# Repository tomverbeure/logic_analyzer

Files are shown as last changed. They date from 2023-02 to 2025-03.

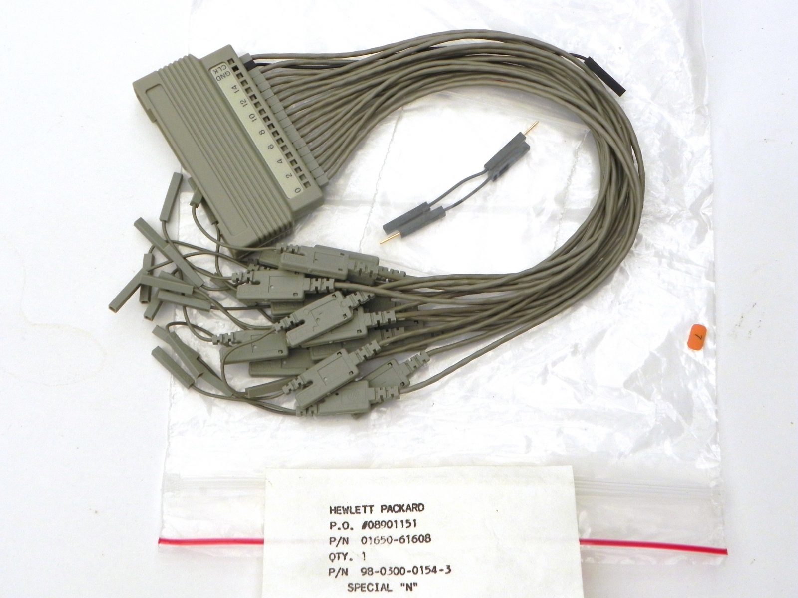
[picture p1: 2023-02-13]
01650-61608-pod.jpg

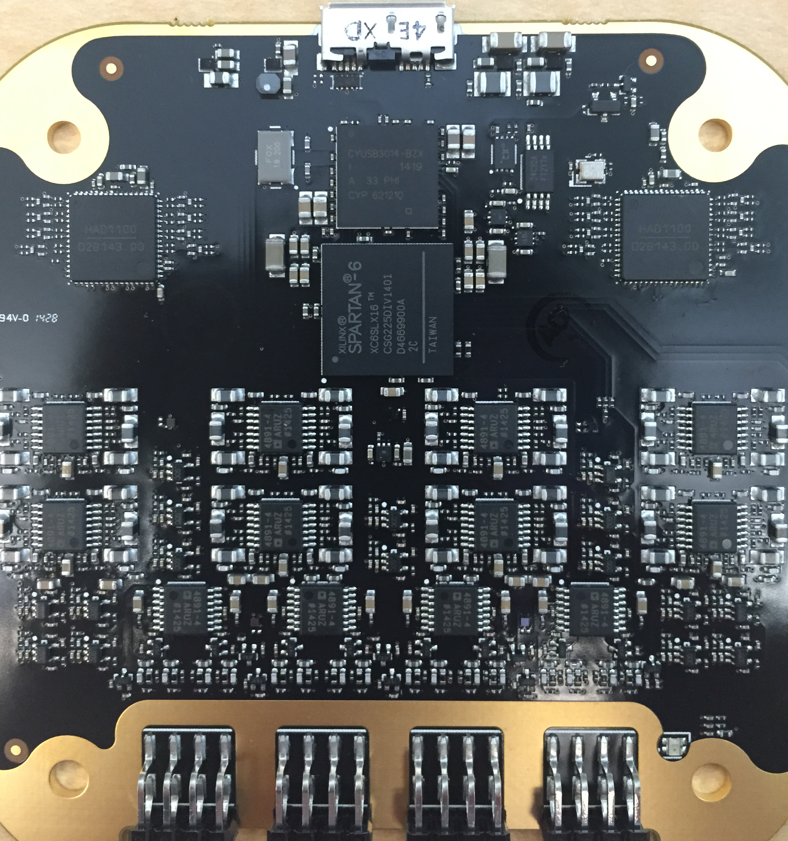
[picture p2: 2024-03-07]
saleae_logic_pro16/Saleae_Logic_Pro_16_PCB_front.jpg

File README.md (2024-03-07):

# logic_analyzer

* [Agilent - Probing Solutions for Logic Analyzers](https://xdevs.com/doc/HP_Agilent_Keysight/agilentprobing.pdf)

    * HP/Agilent 01650-61608 - Sixteen-channel probe lead set
        * Also known as E5383A
        * 40 pins: 16 data input, 1 clk input, 2 +5V, 1 DNC, 18 signal ground, 2 +5V ground
        * RC network: 90k ohm/8.2pF
        * Need board connector that is 0.425" tall
    * [3M 8540-4500PL board connector](https://www.digikey.com/en/products/detail/3m/8540-4500PL/1306252)

* [Bidirectional TVS diode for protecting dual-rail power](https://electronics.stackexchange.com/questions/653141/bidirectional-tvs-diode-for-protecting-dual-rail-power)

# Cyclone II LVDS

* [AN 479: Design Guidelines for Implementing LVDS Interfaces in Cyclone Series Devices](https://www.google.com/url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)

* [Cyclone® II Device Handbook, Volume 1, Chapter 11: High-Speed Differential Interfaces in Cyclone II Devices](https://www.intel.com/content/www/us/en/content-details/655206/cyclone-ii-device-handbook-volume-1-chapter-11-high-speed-differential-interfaces-in-cyclone-ii-device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)

    * RX max 805 Mbps, TX max 640 Mbps.
    * No Vref needed
    * 100 Ohm termination resistor at RX input buffer.
    * (De)serialization is done in core logic.
    * Page 5-63: LVDS receiver timing specification
    * Page 10-27: Pad Placement and DC Guidelines
        * single-ended input no closer than 4 pads away from LVDS I/O
        * single-ended output no closer than 5 pads away from LVDS I/O
        * Maximum 4 155MHz+ LVDS output channels per VCCIO and ground pair
        * Maximum 3 311MHz+ LVDS output channels per VCCIO and ground pair
        * LVDS outputs are 5 or more pads away from LVDS input pad

* [ALTLVDS_TX](https://www.intel.com/content/www/us/en/docs/programmable/683062/17-1/parameter-settings-22420.html)

* [Intel Pin List](https://www.intel.com/content/www/us/en/support/programmable/support-resources/devices/lit-dp.html)

* [LVDS PCB design guidelines](https://madpcb.com/glossary/lvds/)

* [TI - SNx5LVDSxx High-Speed Differential Line Drivers](https://www.ti.com/lit/ds/symlink/sn65lvds31.pdf)

    This datasheet is great for practical layout guidelines. See section 12.

* [TI - LVDS Design Notes](https://www.ti.com/lit/an/slla014a/slla014a.pdf)

    More design guidelines...

* [TI - LVDS Owner’s Manual](https://www.ti.com/lit/ug/snla187/snla187.pdf)

* [LMH7220 - High Speed Comparator with LVDS Outpu](https://www.ti.com/lit/ds/symlink/lmh7322.pdf)

    ~$6 a piece.

* [MAX40025CAWT+T - 280ps High-Speed Comparator, Ultra-Low Dispersion with LVDS Outputs](https://www.mouser.com/datasheet/2/609/MAX40025A_MAX40026-3128703.pdf)

    ~$4.4 a piece for 25+.

# Soldering

* Individual soldering tips on Aliexpress: https://www.aliexpress.us/item/3256802408178790.html
* Drag soldering: https://www.youtube.com/watch?v=5uiroWBkdFY 
* Soldering tips: 
    * Fat/round tip: TS-C4 - reballing
    * Ultra-fin tip: TS-I - fine SMD soldering/fixes
* Mini hotplate
    * https://hackspace.raspberrypi.com/articles/review-miniware-mhp30-mini-hot-plate-preheater
    * 
* BGA Reballing: https://www.youtube.com/watch?v=u8QLlpkyCpc
    * Uses a different jig that doesn't require screws: https://www.aliexpress.us/item/2251832660851140.html
        * magnets
        * rotating knob

* Direct heat reballing (using my jig): https://youtu.be/VTAU647jzzk?t=598
* EP2C35 on AliExpress: https://www.aliexpress.us/item/3256804913471850.html
* 3-in-1 desoldering station: https://www.aliexpress.us/item/3256803049300994.html

# Impedance

* [JLCPCB impedance calculator](https://cart.jlcpcb.com/impedanceCalculation)

    * Impedance + trace space
    * Impedance value: 100 Ohm
    * 4-layer
    * thickness: 1.6mm
    * outer layer (micro-strip)
    * impedance type: differential
    * trace space: 4 mil
    * Result: 
        * JLC3313: 3.49mil  <- chosen
        * JLC7628: 4.96mil
    * Controled impedance PCBs: https://jlcpcb.com/impedance
        * JLC3313
            * Prereg dielectric constant: 4.05
            * Solder mask dielectric constant: 3.8
            * Solder maks thickness: 0.8mil
    
# JLCPCB Plugin

* [Bouni/kicad-jlcpcb-tools](https://github.com/Bouni/kicad-jlcpcb-tools)
* Basic LCSC chips:
    * ESD: SRV05-4-P-T7
    * Voltage inverter: [ICL7660AIBAZA-T](https://www.lcsc.com/product-detail/DC-DC-Converters_RENESAS-ICL7660AIBAZA-T_C7881.html)

# Various

* [Schematic of RISC-V board that uses FT601Q](http://riskfive.com/RiskFive_devel_rev0_board_July_24_2018.pdf)

    * Uses the Xtal that I selected.
    * Uses 25MHz oscillator
    
* ESD info
    * [Littelfuse technical resources](https://www.littelfuse.com/products/tvs-diodes.aspx)
    * USB SS ESD: 
        * [Nexperia PUSB3AB4](https://www.digikey.com/en/products/detail/nexperia-usa-inc/PUSB3AB4Z/6575997)
        * [DigiKey search](https://www.digikey.com/en/products/filter/transient-voltage-suppressors-tvs/tvs-diodes/144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)
    * [Low capacitance 1-channel bidirectional diode: PESD5V0H1BSNYL](https://www.digikey.com/en/products/detail/nexperia-usa-inc/PESD5V0H1BSNYL/12808361)

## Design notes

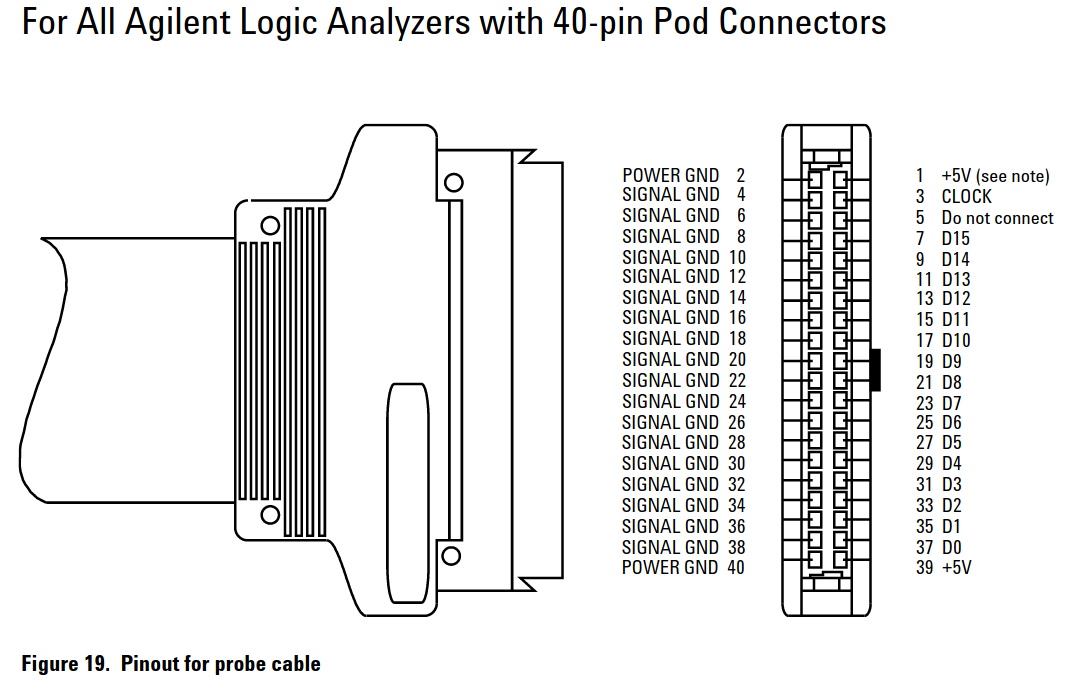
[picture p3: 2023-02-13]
pod_connector_pinout.png

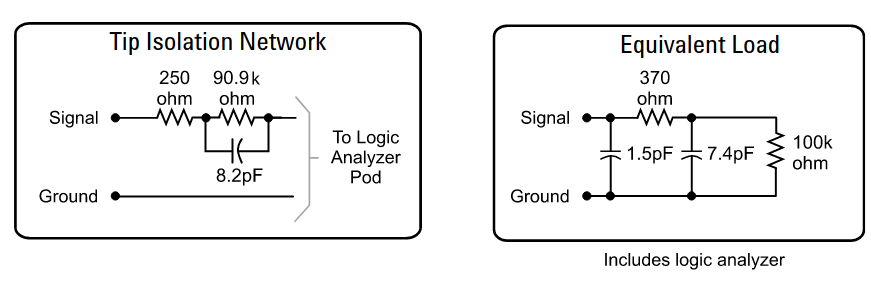
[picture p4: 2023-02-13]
isolation_network.png

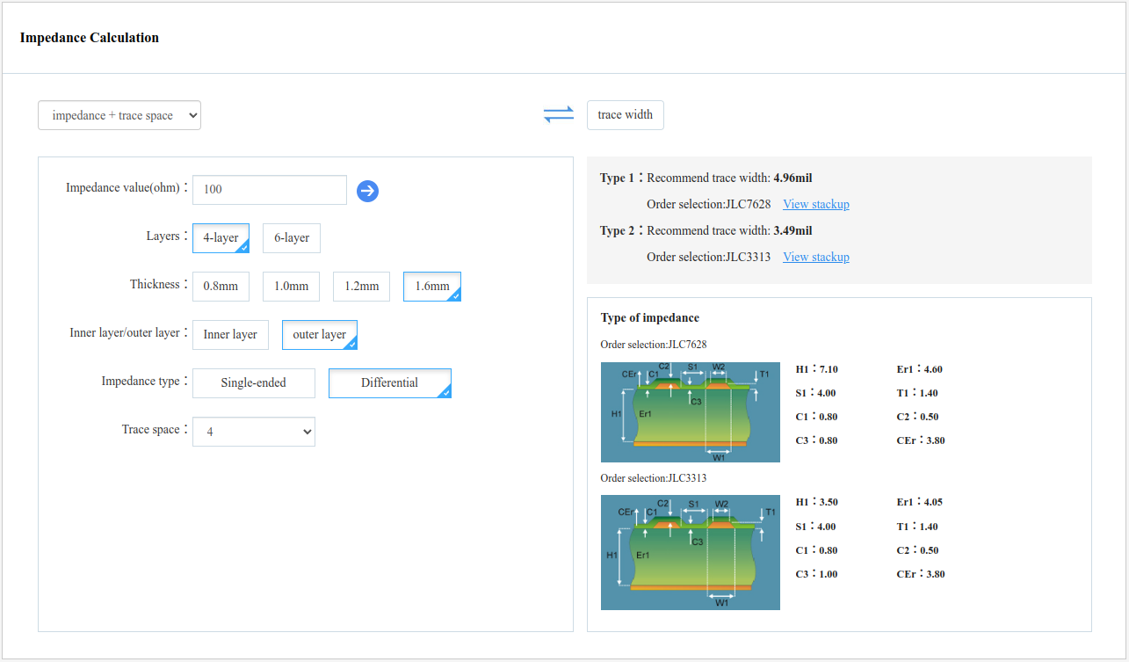
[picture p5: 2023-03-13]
jlcpcb_impedance_calculation.png

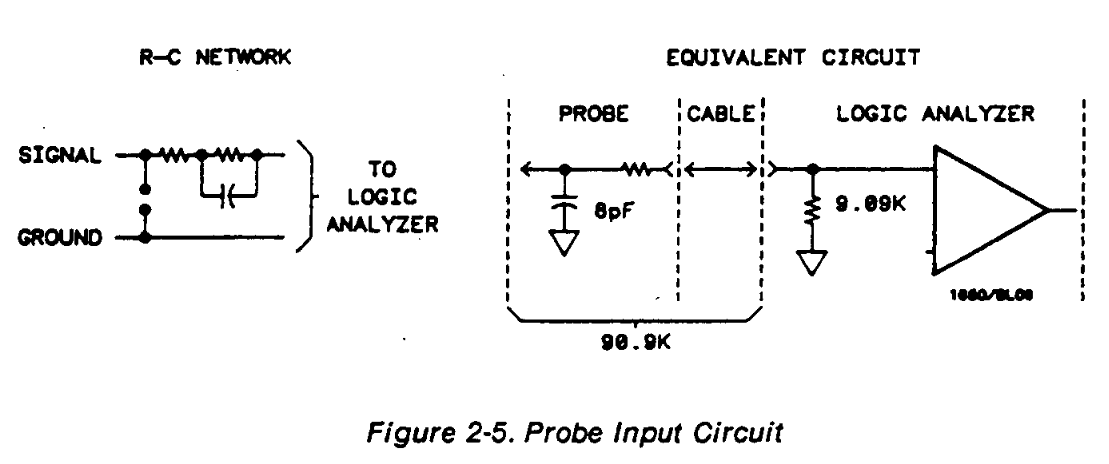
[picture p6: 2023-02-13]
16510a_probe_circuit.png

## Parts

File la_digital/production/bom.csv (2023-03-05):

Designator | Footprint | Quantity | Value | LCSC Part #
C1 | 0402 | 1 | 1n
C10 | 0402 | 1 | 100n
C11 | 0402 | 1 | 100n
C12 | 0402 | 1 | 100n
C13 | 0402 | 1 | 100n
C14 | 0402 | 1 | 100n
C15 | 0402 | 1 | 100n
C16 | 0402 | 1 | 100n
C17 | 0402 | 1 | 100n
C18 | 0402 | 1 | 100n
C19 | 0402 | 1 | 18p
C2 | 0402 | 1 | 100n
C20 | 0402 | 1 | 18p
C21 | 0402 | 1 | 4.7u
C22 | 0402 | 1 | 100n
C23 | 0805 | 1 | 2u
C24 | 1206 | 1 | 47u
C25 | 0805 | 1 | 2u
C26 | 1206 | 1 | 47u
C27 | 0805 | 1 | 1u
C28 | 0805 | 1 | 1u
C29 | 0805 | 1 | 1u
C3 | 0402 | 1 | 1n
C30 | 0805 | 1 | 10u
C31 | 0402 | 1 | 1n
C32 | 0402 | 1 | 100n
C33 | 0402 | 1 | 1n
C34 | 0402 | 1 | 100n
C35 | 0402 | 1 | 1n
C36 | 0402 | 1 | 100n
C37 | 0402 | 1 | 100n
C38 | 0402 | 1 | 100n
C39 | 0402 | 1 | 100n
C4 | 0402 | 1 | 100n
C40 | 0402 | 1 | 100n
C41 | 0402 | 1 | 100n
C42 | 0402 | 1 | 100n
C43 | 0402 | 1 | 100n
C44 | 0402 | 1 | 100n
C45 | 0402 | 1 | 100n
C46 | 0402 | 1 | 100n
C47 | 0402 | 1 | 100n
C48 | 0402 | 1 | 100n
C49 | 0402 | 1 | 100n
C5 | 0402 | 1 | 0.1u
C50 | 0402 | 1 | 100n
C51 | 0402 | 1 | 100n
C52 | 0402 | 1 | 100n
C53 | 0402 | 1 | 100n
C54 | 0402 | 1 | 100n
C55 | 0402 | 1 | 100n
C56 | 0402 | 1 | 100n
C57 | 0402 | 1 | 100n
C58 | 0402 | 1 | 100n
C59 | 0402 | 1 | 100n
C6 | 0402 | 1 | 0.1u
C60 | 0402 | 1 | 100n
C61 | 0402 | 1 | 100n
C62 | 0402 | 1 | 100n
C63 | 0402 | 1 | 100n
C64 | 0402 | 1 | 100n
C65 | 0402 | 1 | 100n
C66 | 0402 | 1 | 100n
C67 | 0402 | 1 | 100n
C68 | 0402 | 1 | 100n
C69 | 0402 | 1 | 100n
C7 | 0402 | 1 | 0.1u
C70 | 0402 | 1 | 100n
C8 | 0402 | 1 | 4.7u
C9 | 0402 | 1 | 100n
FB1 | 0603 | 1 | BLM18PG221SN1D
FB2 | 0603 | 1 | BLM18PG221SN1D
FB3 | 0603 | 1 | BLM18PG221SN1D
J1, J2 | PinHeader_2x21_P1.27mm_Horizontal | 2 | Conn_02x21_Odd_Even
J3 | 3M_8540-4500PL | 1 | 3M_8540-4500PL
J4 | AMPHENOL_GSB343K331HR | 1 | USB3_B_Micro_Amphenol_GSB343K331HR
J5 | PinHeader_2x05_P2.54mm_Vertical | 1 | Conn_02x05_Odd_Even
J6, J7, J8, J9 | PinHeader_1x02_P2.54mm_Vertical | 4 | Conn_01x02_Male
R1 | 0402 | 1 | 1.6k/1%
R10 | 0402 | 1 | 10k
R11 | 0402 | 1 | 100
R12 | 0402 | 1 | 100
R13 | 0402 | 1 | 100
R14 | 0402 | 1 | 100
R15 | 0402 | 1 | 100
R16 | 0402 | 1 | 100
R17 | 0402 | 1 | 100
R18 | 0402 | 1 | 100
R19 | 0402 | 1 | 100
R2 | 0402 | 1 | 10K
R20 | 0402 | 1 | 100
R21 | 0402 | 1 | 100
R22 | 0402 | 1 | 100
R23 | 0402 | 1 | 100
R24 | 0402 | 1 | 100
R25 | 0402 | 1 | 100
R26 | 0402 | 1 | 100
R27 | 0402 | 1 | 100
R28 | 0402 | 1 | 100
R29 | 0402 | 1 | 100
R3 | 0402 | 1 | 10K
R30 | 0402 | 1 | 100
R31 | 0402 | 1 | 10k
R32 | 0402 | 1 | 10k
R33 | 0402 | 1 | 10k
R34 | 0402 | 1 | 10k
R35 | 0402 | 1 | 10k
R36 | 0402 | 1 | 10k
R37 | 0402 | 1 | 10k
R38 | 0402 | 1 | 10k
R39 | 0402 | 1 | 10k
R4 | 0402 | 1 | 10K
R40 | 0402 | 1 | 10k
R41 | 0402 | 1 | 10k
R42 | 0402 | 1 | 10k
R43 | 0402 | 1 | 10k
R44 | 0402 | 1 | 10k
R45 | 0402 | 1 | 10k
R46 | 0402 | 1 | 10k
R47 | 0402 | 1 | 10k
R48 | 0402 | 1 | 10k
R5 | 0402 | 1 | 10K
R6 | 0402 | 1 | 10K
R7 | 0402 | 1 | 10k
R8 | 0402 | 1 | 10k
R9 | 0402 | 1 | 10k
TP1 | TestPoint_Pad_D1.0mm | 1 | TestPoint
U1 | BGA-484_23.0x23.0mm_Layout22x22_P1.0mm | 1 | EP2C5F484
U2 | S-PAK-5 | 1 | MIC37302
U3 | QFN-56-1EP_7x7mm_P0.4mm_FT600Q | 1 | FT600Q-B-T
U4 | SOIC-8_5.23x5.23mm_P1.27mm | 1 | W25Q16JVSNIQ
U5 | SOICN-8LD-PL-1 | 1 | MIC39102
U6 | SOICN-8LD-PL-1 | 1 | MIC49150-1.2
X1 | Oscillator_SMD_IQD_IQXO70-4Pin_7.5x5.0mm | 1 | FNETHE025
Y1 | Crystal_SMD_0603-2Pin_6.0x3.5mm_HandSoldering | 1 | ABM7-30.000MHZ-D2Y-T

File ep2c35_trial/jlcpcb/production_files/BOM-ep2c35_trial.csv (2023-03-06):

Comment | Designator | Footprint | LCSC
1n | C1,C3,C31,C33,C35 | C_0402_1005Metric | C1523
100n | C10,C11,C12,C13,C14,C15,C16,C17,C18,C2,C22,C32,C34,C36,C37,C38,C39,C4,C40,C41,C42,C43,C44,C45,C46,C47,C48,C49,C5,C50,C51,C52,C53,C54,C55,C56,C57,C58,C59,C6,C60,C61,C62,C63,C64,C65,C66,C67,C68,C69,C7,C70,C9 | C_0402_1005Metric | C1525
18p | C19,C20 | C_0402_1005Metric | C1549
10u | C30 | C_0805_2012Metric | C15850
4.7u | C21,C8 | C_0402_1005Metric | C23733
10k | R10,R11,R12,R13,R14,R15,R16,R17,R18,R19,R2,R20,R21,R22,R23,R24,R25,R26,R27,R28,R29,R3,R30,R31,R32,R33,R34,R35,R36,R37,R38,R39,R4,R40,R41,R42,R43,R44,R45,R46,R47,R48,R5,R6,R7,R8,R9 | R_0402_1005Metric | C25744
1u | C27,C28,C29 | C_0805_2012Metric | C28323
2u | C23,C25 | C_0805_2012Metric | C45783
BLM18PG221SN1D | FB1,FB2,FB3 | R_0603_1608Metric | C80165
47u | C24,C26 | C_1206_3216Metric | C96123
Conn_01x02_Male | J6 | PinHeader_1x02_P2.54mm_Vertical
Conn_02x21_Odd_Even | J2 | PinHeader_2x21_P1.27mm_Horizontal
Conn_01x02_Male | J9 | PinHeader_1x02_P2.54mm_Vertical
W25Q16JVSNIQ | U4 | SOIC-8_5.23x5.23mm_P1.27mm
1.6k/1% | R1 | R_0402_1005Metric
Conn_02x05_Odd_Even | J5 | PinHeader_2x05_P2.54mm_Vertical
Conn_02x21_Odd_Even | J1 | PinHeader_2x21_P1.27mm_Horizontal
Conn_01x02_Male | J8 | PinHeader_1x02_P2.54mm_Vertical
USB3_B_Micro_Amphenol_GSB343K331HR | J4 | AMPHENOL_GSB343K331HR
Conn_01x02_Male | J7 | PinHeader_1x02_P2.54mm_Vertical

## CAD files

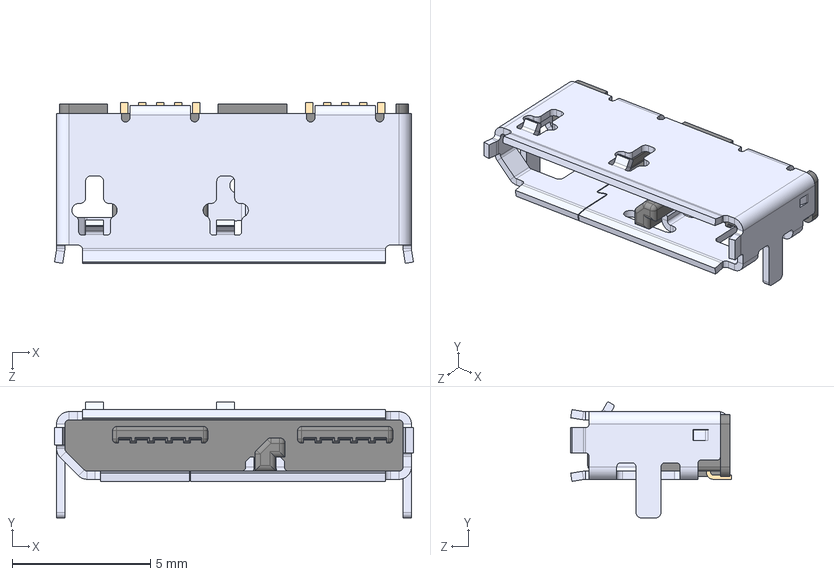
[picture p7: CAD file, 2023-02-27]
logic_analyzer/Amphenol_GSB343K331HR/GSB343K331HR.step
13.0 x 4.20 x 5.82 mm

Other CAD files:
ep2c5_experiments/altera_models/stp1.stp
logic_analyzer/amphenol_usb3microb/footprint.FCStd
ep2c5_experiments/altera_models/stp1_auto_stripped.stp

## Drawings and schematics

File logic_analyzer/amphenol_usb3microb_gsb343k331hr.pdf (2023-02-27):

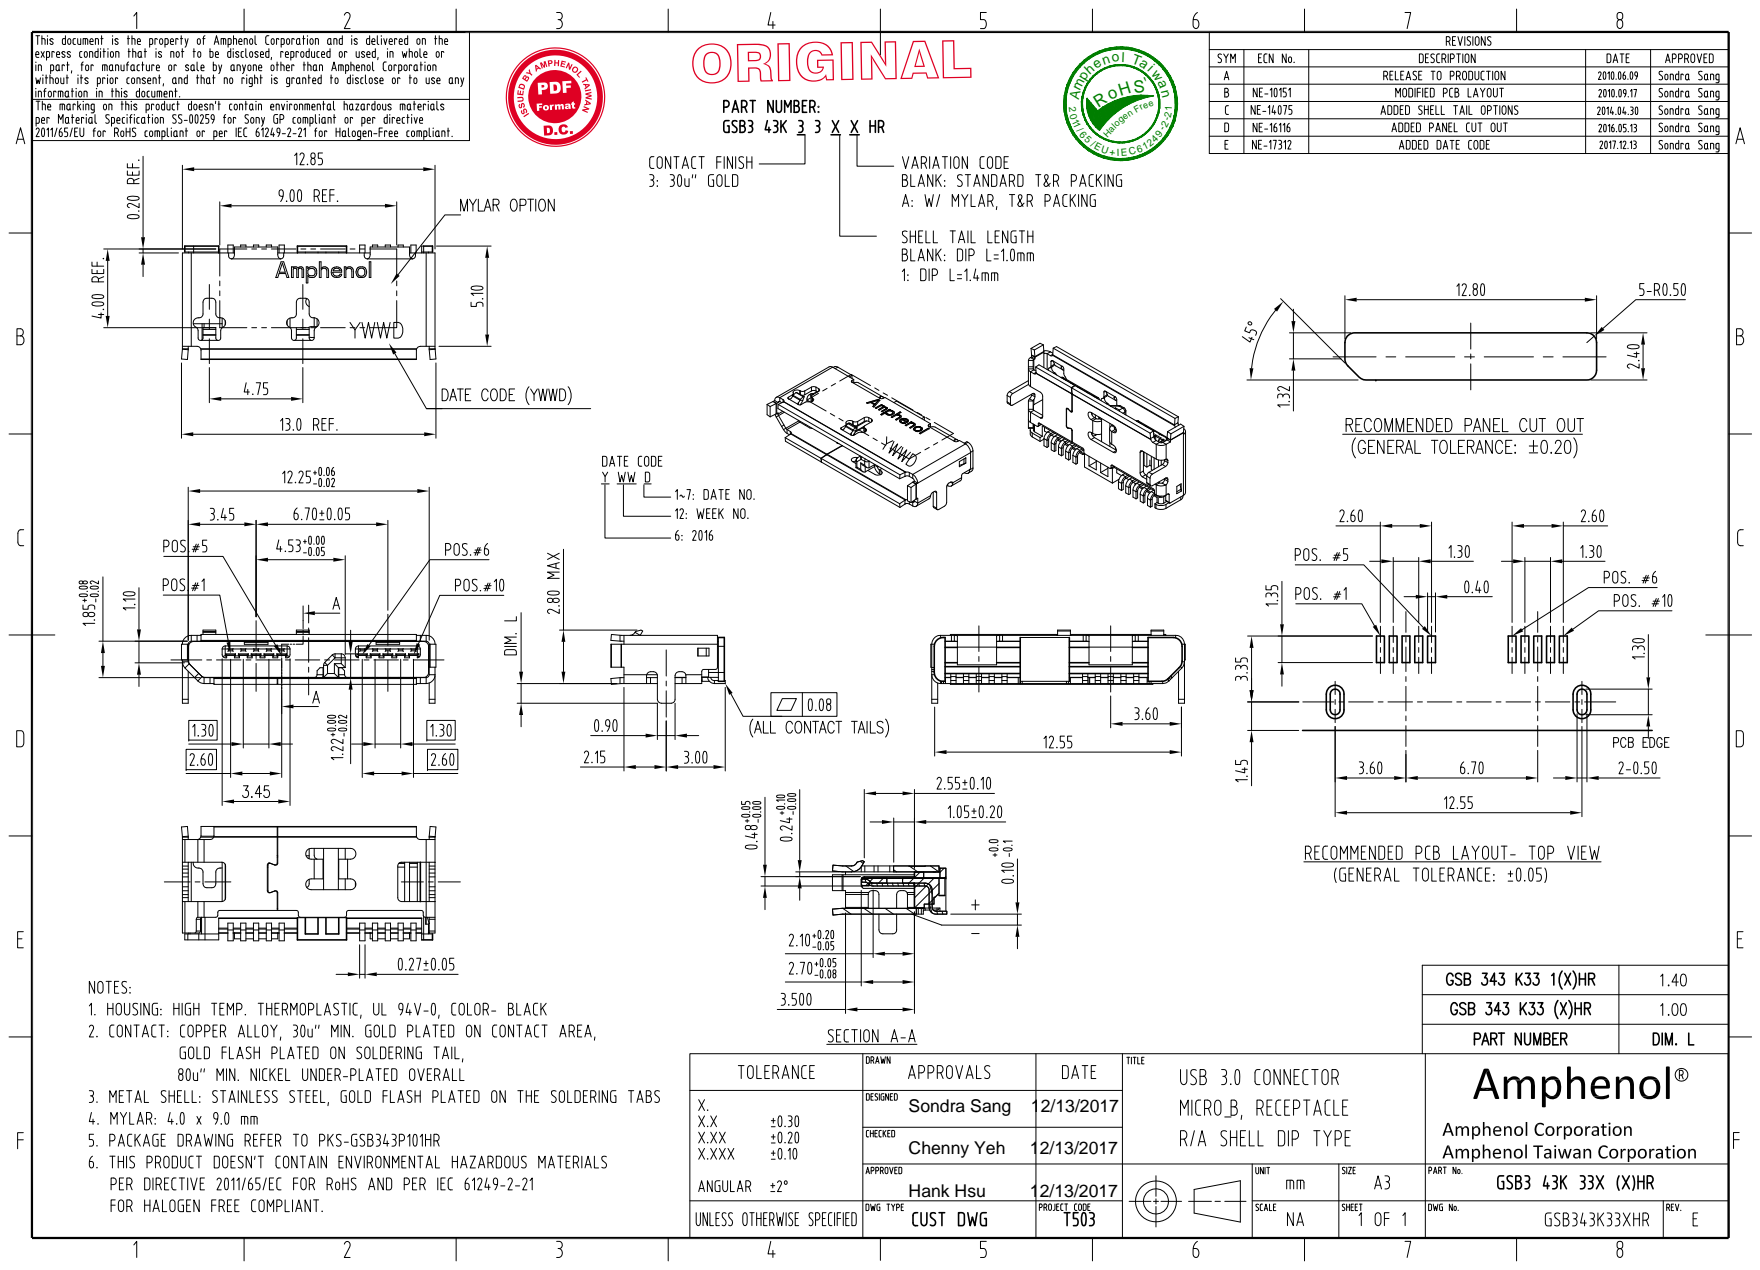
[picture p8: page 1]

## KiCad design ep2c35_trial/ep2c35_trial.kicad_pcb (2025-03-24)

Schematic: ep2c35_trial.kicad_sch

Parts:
C1, C3, C31, C33, C35: 1n; C_0402_1005Metric
C2, C4, C9, C10, C11, C12, C13, C14, C15, C16, C17, C18, C21, C22, C32, C34, C36, C37, C38, C39, C40, C41, C42, C43, C44, C45, C46, C47, C48, C49, C50, C51, C52, C53, C54, C55, C56, C57, C58, C59, C60, C61, C62, C63, C64, C65, C66, C67, C68, C69, C70, C72: 100n; C_0402_1005Metric
C5, C6, C7: 0.1u; C_0402_1005Metric
C8: 4.7u; C_0402_1005Metric
C19, C20: 18p; C_0402_1005Metric
C23, C25: 2u; C_0805_2012Metric
C24, C26: 47u; C_1206_3216Metric
C27, C28, C29, C71, C73: 1u; C_0805_2012Metric
C30: 10u; C_0805_2012Metric
D1, D3, D4, D5, D6, D7, D8: LED; LED_0603_1608Metric
FB1, FB2, FB3: BLM18PG221SN1D; R_0603_1608Metric
J1, J2: Conn_02x21_Odd_Even; PinHeader_2x21_P1.27mm_Horizontal
J3: 3M_8540-4500PL
J4: USB3_B_Micro_Amphenol_GSB343K331HR; AMPHENOL_GSB343K331HR
J5: Conn_02x05_Odd_Even; PinHeader_2x05_P2.54mm_Vertical
J7, J11: Conn_01x03_Pin; PinHeader_1x03_P2.54mm_Vertical
J8, J9: Conn_01x02_Male; PinHeader_1x02_P2.54mm_Vertical
J10: Conn_02x10_Odd_Even; PinHeader_2x10_P1.27mm_Horizontal
R1: 1.6k/1%; R_0402_1005Metric
R2, R3, R4, R5, R6, R7, R10, R31, R32, R33, R34, R35, R36, R37, R38, R39, R40, R41, R42, R43, R44, R45, R46, R47, R48: 10k; R_0402_1005Metric
R8, R68, R69, R71: 5k; R_0402_1005Metric
R9, R72: 3k; R_0402_1005Metric
R11, R12, R13, R14, R15, R16, R17, R18, R19, R20, R21, R22, R23, R24, R25, R26, R27, R28, R29, R30: 100; R_0402_1005Metric
R49, R51, R52, R53, R54, R55, R70: 1k; R_0402_1005Metric
R56, R58, R59, R61, R62, R64, R65, R67: 120; R_0402_1005Metric
R57, R60, R63, R66: 170; R_0402_1005Metric
TP1: TestPoint; TestPoint_Pad_D1.0mm
U1: EP2C35F484; BGA-484_23.0x23.0mm_Layout22x22_P1.0mm
U2: MIC37302; S-PAK-5
U3: FT600Q-B-T; QFN-56-1EP_7x7mm_P0.4mm_FT600Q
U4: W25Q16JVSNIQ; SOIC-8_5.23x5.23mm_P1.27mm
U5: MIC39102; SOICN-8LD-PL-1
U6: MIC49150-1.2; SOICN-8LD-PL-1
U7: SP3003-02UTG; SOT-23-6
U8, U9, U10, U11, U17: SRV05-4; SOT-23-6
U12, U13: LM317_TO-252; TO-252-2
X1: FNETHE025; Oscillator_SMD_IQD_IQXO70-4Pin_7.5x5.0mm
Y1: ABM7-30.000MHZ-D2Y-T; Crystal_SMD_0603-2Pin_6.0x3.5mm_HandSoldering

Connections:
+1V0: C8.2, C16.2, C17.2, C18.2, U3.1 (AVDD), U3.23 (VD10), U3.26 (VD10), U3.31 (DV10), U3.37 (VD10), U3.50 (VD10)
+1V2: C3.1, C4.1, C37.1, C38.1, C39.1, C40.1, C41.1, C42.1, C43.1, C44.1, C45.1, C46.1, C47.1, C48.1, C49.1, D3.2 (A), J8.2, J9.1, U1.E5 (VCCD_PLL3), U1.F17 (VCCD_PLL2), U1.G8 (VCCINT), U1.G12 (VCCINT), U1.H8 (VCCINT), U1.H12 (VCCINT), U1.H13 (VCCINT), U1.J10 (VCCINT), U1.J11 (VCCINT), U1.J12 (VCCINT), U1.J13 (VCCINT), U1.K8 (VCCINT), U1.K9 (VCCINT), U1.K14 (VCCINT), U1.L9 (VCCINT), U1.L14 (VCCINT), U1.L16 (VCCINT), U1.M9 (VCCINT), U1.M14 (VCCINT), U1.N9 (VCCINT), U1.N14 (VCCINT), U1.P10 (VCCINT), U1.P11 (VCCINT), U1.P12 (VCCINT), U1.P13 (VCCINT), U1.P14 (VCCINT), U1.R10 (VCCINT), U1.R12 (VCCINT), U1.T12 (VCCINT), U1.T15 (VCCINT), U1.U6 (VCCD_PLL1), U1.U17 (VCCD_PLL4)
+1V2A: C1.1, C2.1, C30.2, C31.1, C32.1, C33.1, C34.1, C35.1, C36.1, FB3.2, U1.E6 (VCCA_PLL3), U1.F16 (VCCA_PLL2), U1.U7 (VCCA_PLL1), U1.U16 (VCCA_PLL4)
+2V5: C28.2, C50.1, C51.1, C52.1, C53.1, C54.1, C55.1, C56.1, C57.1, C58.1, C59.1, C69.1, D1.2 (A), J11.2, R5.1, R6.1, U1.AA1 (VCCIO1), U1.AA22 (VCCIO6), U1.AB2 (VCCIO8), U1.AB21 (VCCIO7), U1.M3 (VCCIO1), U1.M20 (VCCIO6), U1.P7 (VCCIO1), U1.P16 (VCCIO6), U1.T4 (VCCIO1), U1.T9 (VCCIO8), U1.T14 (VCCIO7), U1.T19 (VCCIO6), U1.V10 (VCCIO8), U1.V13 (VCCIO7), U1.W6 (VCCIO8), U1.W17 (VCCIO7), U1.Y11 (VCCIO8), U1.Y12 (VCCIO7), U6.3 (VIN)
+3.3V: C9.2, C10.2, C11.2, C12.2, C13.2, C14.2, C15.2, C21.1, C22.2, C25.2, C27.2, C60.1, C61.1, C62.1, C63.1, C64.1, C65.1, C66.1, C67.1, C68.1, C70.1, D8.2 (A), J5.4, J7.2, R2.1, R3.2, R4.2, R7.2, U1.A2 (VCCIO3), U1.A21 (VCCIO4), U1.B1 (VCCIO2), U1.B22 (VCCIO5), U1.C6 (VCCIO3), U1.C11 (VCCIO3), U1.C12 (VCCIO4), U1.D17 (VCCIO4), U1.E10 (VCCIO3), U1.E13 (VCCIO4), U1.G9 (VCCIO3), U1.G14 (VCCIO4), U1.G19 (VCCIO5), U1.J7 (VCCIO2), U1.J16 (VCCIO5), U1.L3 (VCCIO2), U1.L20 (VCCIO5), U3.15 (VCC33), U3.19 (VCC33), U3.22 (VDDA), U3.30 (VCC33), U3.38 (VCCIO), U3.44 (VCCIO), U3.52 (VCCIO), U4.8 (VCC), U5.1 (EN), U5.2 (IN), U6.1 (EN), U6.2 (VBIAS), U12.3 (VI), X1.4 (Vdd)
/1V2_LDO: C29.2, J8.1, U6.4 (VOUT)
/1V2_OPT: FB3.1, J9.2
/2V5_ADJ: R10.1, R31.2, U5.4 (ADJ)
/2V5_ADJ_LM: R68.1, R69.2, U12.1 (ADJ)
/2V5_LDO: C26.2, J11.1, R10.2, U5.3 (OUT)
/2V5_LM_LDO: C71.2, J11.3, R68.2, U12.2 (VO)
/3V3_ADJ: R8.1, R9.2, U2.5 (ADJ)
/3V3_ADJ_LM: R71.1, R72.2, U13.1 (ADJ)
/3V3_LDO: C24.2, J7.1, R8.2, U2.4 (VOUT)
/3V3_LM_LDO: C73.2, J7.3, R71.2, U13.2 (VO)
/CLK25: U1.A12 (CLK9/LVDSCLK4p/input), X1.3 (OUT)
/CONF_DONE: R6.2, U1.N18 (CONF_DONE)
/CRC_ERROR: TP1.1, U1.D3 (IO/CRC_ERROR/LVDS49p)
/DIG_CLK: R32.1, U1.L22 (CLK4/LVDSCLK2p/input)
/DIG_D0: R48.1, U1.C21 (IO/LVDS104n)
/DIG_D1: R47.1, U1.C22 (IO/LVDS104p)
/DIG_D2: R46.1, U1.D21 (IO/LVDS108n)
/DIG_D3: R45.1, U1.D22 (IO/LVDS108p)
/DIG_D4: R44.1, U1.E21 (IO/LVDS109n)
/DIG_D5: R43.1, U1.E22 (IO/LVDS109p)
/DIG_D6: R42.1, U1.F21 (IO/LVDS112n)
/DIG_D7: R41.1, U1.F22 (IO/LVDS112p)
/DIG_D8: R40.1, U1.G21 (IO/LVDS114n)
/DIG_D9: R39.1, U1.G22 (IO/LVDS114p)
/DIG_D10: R38.1, U1.H21 (IO/LVDS122n)
/DIG_D11: R37.1, U1.H22 (IO/LVDS122p)
/DIG_D12: R36.1, U1.J21 (IO/LVDS124n)
/DIG_D13: R35.1, U1.J22 (IO/LVDS124p)
/DIG_D14: R34.1, U1.K21 (IO/LVDS125n)
/DIG_D15: R33.1, U1.K22 (IO/LVDS125p)
/FT_BE0: U1.A8 (IO/LVDS62p), U3.2 (BE_0)
/FT_BE1: U1.B8 (IO/LVDS62n), U3.3 (BE_1)
/FT_CLK: U1.B3 (IO/DEV_CLRn/LVDS50n), U3.43 (CLK)
/FT_DATA0: U1.F2 (IO/LVDS36n), U3.33 (DATA_0)
/FT_DATA1: U1.E1 (IO/LVDS37p), U3.34 (DATA_1)
/FT_DATA2: U1.E2 (IO/LVDS37n), U3.35 (DATA_2)
/FT_DATA3: U1.D1 (IO/LVDS40p), U3.36 (DATA_3)
/FT_DATA4: U1.D2 (IO/LVDS40n), U3.39 (DATA_4)
/FT_DATA5: U1.C1 (IO/LVDS47p), U3.40 (DATA_5)
/FT_DATA6: U1.C2 (IO/LVDS47n), U3.41 (DATA_6)
/FT_DATA7: U1.A3 (IO/LVDS50p), U3.42 (DATA_7)
/FT_DATA8: U1.A4 (IO/LVDS51p), U3.45 (DATA_8)
/FT_DATA9: U1.B4 (IO/LVDS51n), U3.46 (DATA_9)
/FT_DATA10: U1.A5 (IO/LVDS52p), U3.47 (DATA_10)
/FT_DATA11: U1.B5 (IO/LVDS52n), U3.48 (DATA_11)
/FT_DATA12: U1.A6 (IO/LVDS53p), U3.53 (DATA_12)
/FT_DATA13: U1.B6 (IO/LVDS53n), U3.54 (DATA_13)
/FT_DATA14: U1.A7 (IO/LVDS61p), U3.55 (DATA_14)
/FT_DATA15: U1.B7 (IO/LVDS61n), U3.56 (DATA_15)
/FT_GPIO0: U1.D9 (IO/LVDS64p), U3.12 (GPIO0)
/FT_GPIO1: U1.C10 (IO/VREFB3N0), U3.13 (GPIO1)
/FT_OE_N: U1.A11 (IO/LVDS73p), U3.9 (OE_N)
/FT_RD_N: U1.B10 (IO/LVDS70n), U3.8 (RD_N)
/FT_RESET_N: U1.B11 (IO/LVDS73n), U3.10 (RESET_N)
/FT_RXF_N: U1.B9 (IO/LVDS67n), U3.5 (RXF_N)
/FT_SIWU_N: R7.1, U3.6 (SIWU_N)
/FT_TXE_N: U1.A9 (IO/LVDS67p), U3.4 (TXE_N)
/FT_WAKEUP_N: U1.C9 (IO/LVDS59p), U3.11 (WAKEUP_N)
/FT_WR_N: U1.A10 (IO/LVDS70p), U3.7 (WR_N)
/LED0: D4.2 (A), U1.G1 (IO/LVDS31p)
/LED1: D5.2 (A), U1.G2 (IO/LVDS31n)
/LED2: D6.2 (A), U1.H1 (IO/LVDS29p)
/LED3: D7.2 (A), U1.H2 (IO/LVDS29n)
/LVDS2: U1.W3 (IO/LVDS2p), U1.W4 (IO/LVDS2n)
/LVDS7: U1.T5 (IO/LVDS7p), U1.T6 (IO/LVDS7n)
/LVDS10: U1.R5 (IO/LVDS10p), U1.R6 (IO/LVDS10n)
/LVDS12: U1.P4 (IO/LVDS12p), U1.R4 (IO/LVDS12n)
/LVDS17: U1.P5 (IO/LVDS17p), U1.P6 (IO/LVDS17n)
/LVDS18: U1.R7 (IO/LVDS18n), U1.R8 (IO/LVDS18p)
/LVDS20: U1.N3 (IO/LVDS20p), U1.N4 (IO/LVDS20n)
/LVDS22: U1.N5 (IO/LVDS22n), U1.N6 (IO/LVDS22p)
/LVDS23: U1.M7 (IO/LVDS23n), U1.M8 (IO/LVDS23p)
/LVDS26: U1.M5 (IO/LVDS26p), U1.M6 (IO/LVDS26n)
/LVDS48: U1.E3 (IO/LVDS48p), U1.E4 (IO/LVDS48n)
/LVDS76: U1.A14 (IO/LVDS76p), U1.B14 (IO/LVDS76n)
/LVDS96: U1.A18 (IO/LVDS96p), U1.B18 (IO/LVDS96n)
/LVDS97: U1.A19 (IO/LVDS97p), U1.B19 (IO/LVDS97n)
/LVDS98: U1.A20 (IO/LVDS98p), U1.B20 (IO/LVDS98n)
/LVDS100: U1.D19 (IO/LVDS100n), U1.D20 (IO/LVDS100p)
/LVDS101: U1.C19 (IO/LVDS101n), U1.C20 (IO/LVDS101p)
/LVDS105: U1.E20 (IO/LVDS105n), U1.F20 (IO/LVDS105p)
/LVDS111: U1.H17 (IO/LVDS111p), U1.H18 (IO/LVDS111n)
/LVDS117: U1.J18 (IO/LVDS117p), U1.J19 (IO/LVDS117n)
/LVDS120: U1.H19 (IO/LVDS120p), U1.J20 (IO/LVDS120n)
/LVDS130: U1.M15 (IO/LVDS130p), U1.M16 (IO/LVDS130n)
/LVDS132: U1.N15 (IO/LVDS132p), U1.P15 (IO/LVDS132n)
/LVDS152: U1.AA19 (IO/LVDS152n), U1.AB19 (IO/LVDS152p)
/LVDS168: U1.AA16 (IO/LVDS168n), U1.AB16 (IO/LVDS168p)
/LVDS169: U1.AA15 (IO/LVDS169n), U1.AB15 (IO/LVDS169p)
/LVDS170: U1.AA14 (IO/LVDS170n), U1.AB14 (IO/LVDS170p)
/LVDS174: U1.AA13 (IO/LVDS174n), U1.AB13 (IO/LVDS174p)
/LVDS176: U1.AA12 (IO/LVDS176n), U1.AB12 (IO/LVDS176p)
/LVDS177: U1.AA11 (IO/LVDS177n), U1.AB11 (IO/LVDS177p)
/LVDS197: U1.AA5 (IO/LVDS197n), U1.AB5 (IO/LVDS197p)
/LVDS198: U1.Y5 (IO/LVDS198p), U1.Y6 (IO/LVDS198n)
/LVDS_RX_CLK0_N: J1.39, R30.1, U1.M2 (CLK3/LVDSCLK1n/input)
/LVDS_RX_CLK0_P: J1.41, R30.2, U1.M1 (CLK2/LVDSCLK1p/input)
/LVDS_RX_CLK1_N: J2.39, R20.1, U1.M21 (CLK7/LVDSCLK3n/input)
/LVDS_RX_CLK1_P: J2.41, R20.2, U1.M22 (CLK6/LVDSCLK3p/input)
/LVDS_RX_DATA0_0_N: J1.35, R28.1, U1.N2 (IO/LVDS25n)
/LVDS_RX_DATA0_0_P: J1.37, R28.2, U1.N1 (IO/LVDS25p)
/LVDS_RX_DATA0_1_N: J1.31, R27.1, U1.P2 (IO/LVDS24n)
/LVDS_RX_DATA0_1_P: J1.33, R27.2, U1.P1 (IO/LVDS24p)
/LVDS_RX_DATA0_2_N: J1.27, R26.1, U1.R2 (IO/LVDS16n)
/LVDS_RX_DATA0_2_P: J1.29, R26.2, U1.R1 (IO/LVDS16p)
/LVDS_RX_DATA0_3_N: J1.23, R25.1, U1.T2 (IO/LVDS13n)
/LVDS_RX_DATA0_3_P: J1.25, R25.2, U1.T1 (IO/LVDS13p)
/LVDS_RX_DATA0_4_N: J1.19, R24.1, U1.U2 (IO/LVDS11n)
/LVDS_RX_DATA0_4_P: J1.21, R24.2, U1.U1 (IO/LVDS11p)
/LVDS_RX_DATA0_5_N: J1.15, R23.1, U1.V2 (IO/LVDS8n)
/LVDS_RX_DATA0_5_P: J1.17, R23.2, U1.V1 (IO/LVDS8p)
/LVDS_RX_DATA0_6_N: J1.11, R22.1, U1.W2 (IO/LVDS6n)
/LVDS_RX_DATA0_6_P: J1.13, R22.2, U1.W1 (IO/LVDS6p)
/LVDS_RX_DATA0_7_N: J1.7, R21.1, U1.Y2 (IO/LVDS5n)
/LVDS_RX_DATA0_7_P: J1.9, R21.2, U1.Y1 (IO/LVDS5p)
/LVDS_RX_DATA1_0_N: J2.31, R18.1, U1.Y21 (IO/LVDS141n)
/LVDS_RX_DATA1_0_P: J2.33, R18.2, U1.Y22 (IO/LVDS141p)
/LVDS_RX_DATA1_1_N: J2.27, R17.1, U1.W21 (IO/LVDS145n)
/LVDS_RX_DATA1_1_P: J2.29, R17.2, U1.W22 (IO/LVDS145p)
/LVDS_RX_DATA1_2_N: J2.23, R16.1, U1.V21 (IO/LVDS140n)
/LVDS_RX_DATA1_2_P: J2.25, R16.2, U1.V22 (IO/LVDS140p)
/LVDS_RX_DATA1_3_N: J2.19, R15.1, U1.U21 (IO/LVDS139n)
/LVDS_RX_DATA1_3_P: J2.21, R15.2, U1.U22 (IO/LVDS139p)
/LVDS_RX_DATA1_4_N: J2.15, R14.1, U1.T21 (IO/LVDS135n)
/LVDS_RX_DATA1_4_P: J2.17, R14.2, U1.T22 (IO/LVDS135p)
/LVDS_RX_DATA1_5_N: J2.11, R13.1, U1.R21 (IO/LVDS134n)
/LVDS_RX_DATA1_5_P: J2.13, R13.2, U1.R22 (IO/LVDS134p)
/LVDS_RX_DATA1_6_N: J2.7, R12.1, U1.P21 (IO/LVDS129n)
/LVDS_RX_DATA1_6_P: J2.9, R12.2, U1.P22 (IO/LVDS129p)
/LVDS_RX_DATA1_7_N: J2.3, R11.1, U1.N21 (IO/LVDS128n)
/LVDS_RX_DATA1_7_P: J2.5, R11.2, U1.N22 (IO/LVDS128p)
/LVDS_RX_FCLK0_N: J1.3, R29.1, U1.Y4 (IO/LVDS0n)
/LVDS_RX_FCLK0_P: J1.5, R29.2, U1.Y3 (IO/LVDS0p)
/LVDS_RX_FCLK1_N: J2.35, R19.1, U1.Y19 (IO/LVDS149n)
/LVDS_RX_FCLK1_P: J2.37, R19.2, U1.Y20 (IO/LVDS149p)
/LVDS_TX_DATA0_N: J10.5, R56.1, R57.2
/LVDS_TX_DATA0_P: J10.3, R57.1, R58.1
/LVDS_TX_DATA0_RAW_N: R56.2, U1.AA10 (IO/LVDS178n)
/LVDS_TX_DATA0_RAW_P: R58.2, U1.AB10 (IO/LVDS178p)
/LVDS_TX_DATA1_N: J10.9, R59.1, R60.2
/LVDS_TX_DATA1_P: J10.7, R60.1, R61.1
/LVDS_TX_DATA1_RAW_N: R59.2, U1.AA9 (IO/LVDS181n)
/LVDS_TX_DATA1_RAW_P: R61.2, U1.AB9 (IO/LVDS181p)
/LVDS_TX_DATA2_N: J10.13, R62.1, R63.2
/LVDS_TX_DATA2_P: J10.11, R63.1, R64.1
/LVDS_TX_DATA2_RAW_N: R62.2, U1.AA8 (IO/LVDS183n)
/LVDS_TX_DATA2_RAW_P: R64.2, U1.AB8 (IO/LVDS183p)
/LVDS_TX_DATA3_N: J10.17, R65.1, R66.2
/LVDS_TX_DATA3_P: J10.15, R66.1, R67.1
/LVDS_TX_DATA3_RAW_N: R65.2, U1.AA7 (IO/LVDS189n)
/LVDS_TX_DATA3_RAW_P: R67.2, U1.AB7 (IO/LVDS189p)
/POD_CLK: J3.3 (CLOCK), R32.2, U11.1 (IO1)
/POD_D0: J3.37 (D0), R48.2, U17.1 (IO1)
/POD_D1: J3.35 (D1), R47.2, U17.3 (IO2)
/POD_D2: J3.33 (D2), R46.2, U17.4 (IO3)
/POD_D3: J3.31 (D3), R45.2, U17.6 (IO4)
/POD_D4: J3.29 (D4), R44.2, U8.1 (IO1)
/POD_D5: J3.27 (D5), R43.2, U8.3 (IO2)
/POD_D6: J3.25 (D6), R42.2, U8.4 (IO3)
/POD_D7: J3.23 (D7), R41.2, U8.6 (IO4)
/POD_D8: J3.21 (D8), R40.2, U9.1 (IO1)
/POD_D9: J3.19 (D9), R39.2, U9.3 (IO2)
/POD_D10: J3.17 (D10), R38.2, U9.4 (IO3)
/POD_D11: J3.15 (D11), R37.2, U9.6 (IO4)
/POD_D12: J3.13 (D12), R36.2, U10.1 (IO1)
/POD_D13: J3.11 (D13), R35.2, U10.3 (IO2)
/POD_D14: J3.9 (D14), R34.2, U10.4 (IO3)
/POD_D15: J3.7 (D15), R33.2, U10.6 (IO4)
/SPI_ADS: U1.C4 (IO/ASDO), U4.5 (DI(IO0))
/SPI_DATA0: U1.K4 (DATA0), U4.2 (DO(IO1))
/SPI_DCLK: U1.L6 (DCLK), U4.6 (CLK)
/SPI_nCS: U1.C3 (IO/nCSO), U4.1 (~CS)
/SPI_nRESET: R4.1, U4.7 (IO3)
/SPI_nWP: R3.1, U4.3 (IO2)
/TCK: J5.1, U1.K2 (TCK)
/TDI: J5.9, U1.K5 (TDI)
/TDO: J5.3, U1.L5 (TDO)
/TMS: J5.5, U1.K6 (TMS)
/USB_D_N: J4.2 (D-), U3.20 (DM), U7.1, U7.6
/USB_D_P: J4.3 (D+), U3.18 (DP), U7.2, U7.5
/USB_RREF: R1.1, U3.21 (RREF)
/USB_SHIELD: FB2.1, J4.S1 (SHIELD), J4.S2 (SHIELD)
/USB_SSRX_N: J4.9 (SSRX-), U3.27 (RIDN)
/USB_SSRX_P: J4.10 (SSRX+), U3.28 (RIDP)
/USB_SSTX_N: C6.2, U3.24 (TODN)
/USB_SSTX_P: C7.2, U3.25 (TODP)
/USB_SSTX_RAW_N: C6.1, J4.6 (SSTX-)
/USB_SSTX_RAW_P: C7.1, J4.7 (SSTX+)
/VBUS: C23.2, C72.1, FB1.1, J3.1 (+5V), J3.39 (+5V), U2.1 (EN), U2.2 (VIN), U3.29 (VBUS), U13.3 (VI)
/VBUS_RAW: C5.1, FB1.2, J4.1 (VBUS)
/nSTATUS: R5.2, U1.N20 (nSTATUS)
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

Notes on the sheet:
Vout=1.25(1+R1/R2) + Iadj*R2 -> 2.5V
Vout=1.24(1+R1/R2) -> 3.3V
Vout=1.24(1+R1/R2) -> 2.48V

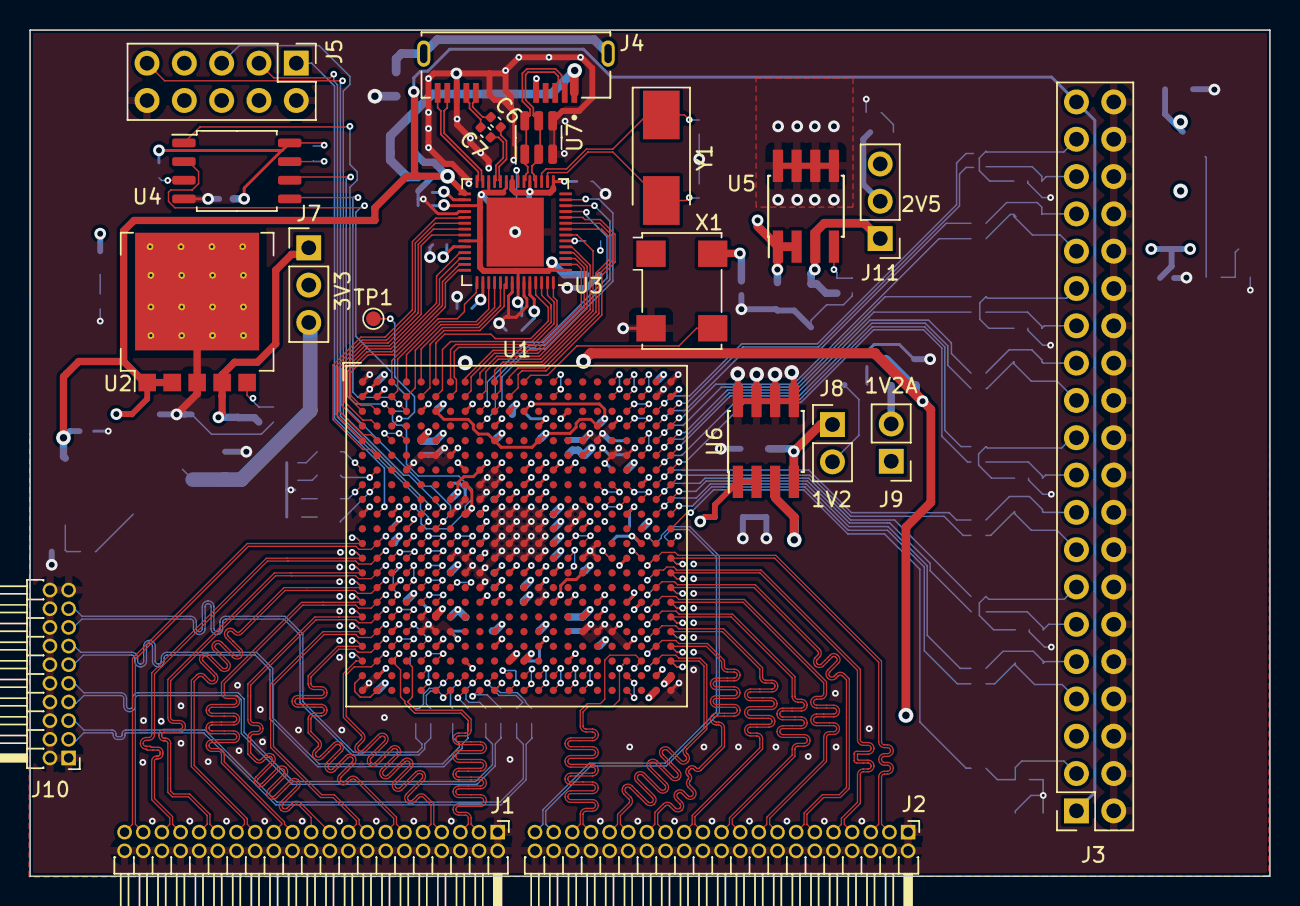
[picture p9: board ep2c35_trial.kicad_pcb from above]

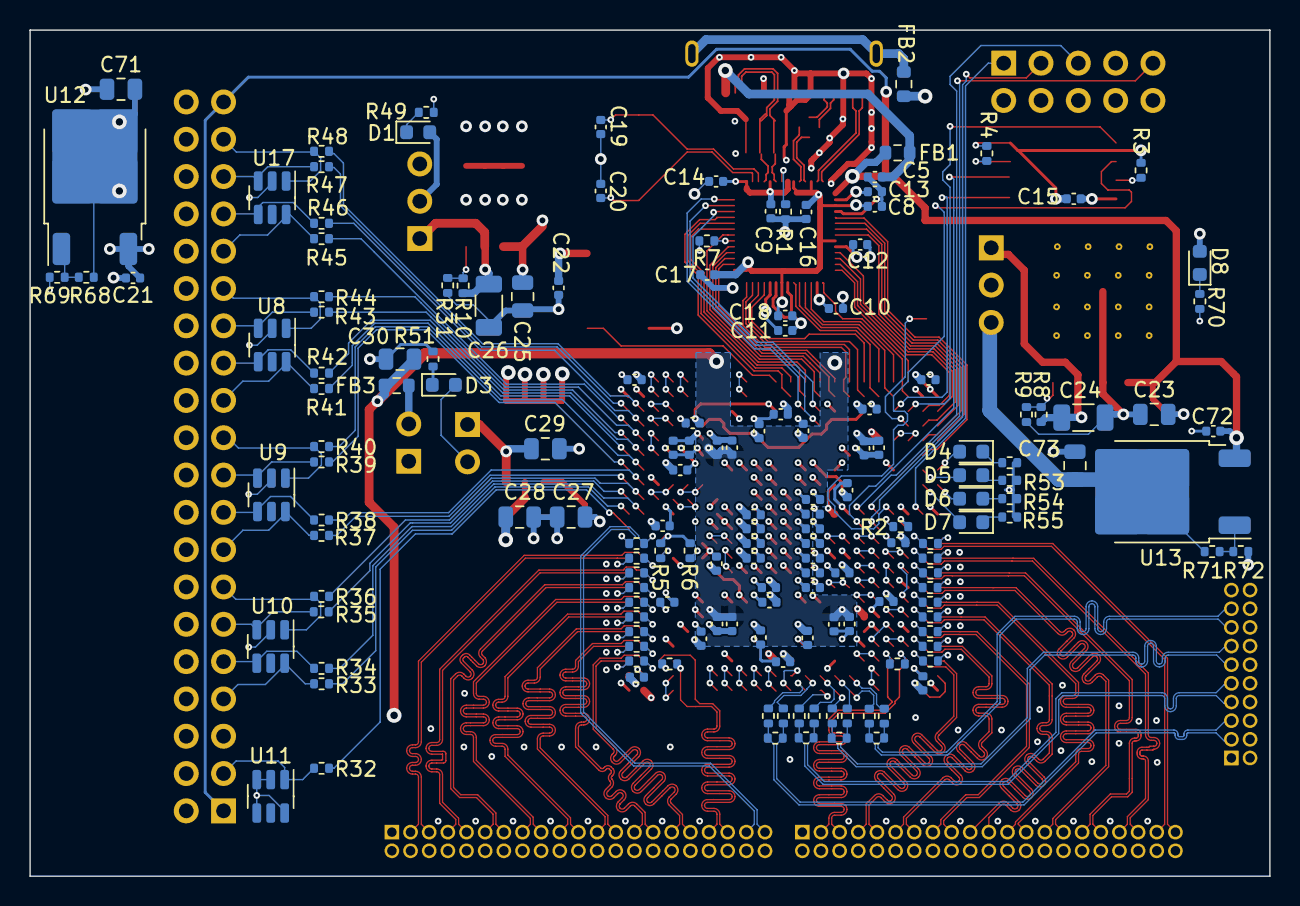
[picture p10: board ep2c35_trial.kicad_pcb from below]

Board: 4 copper layers, 84.4 x 57.6 mm, 181 parts (159 on the bottom side), 210 nets.

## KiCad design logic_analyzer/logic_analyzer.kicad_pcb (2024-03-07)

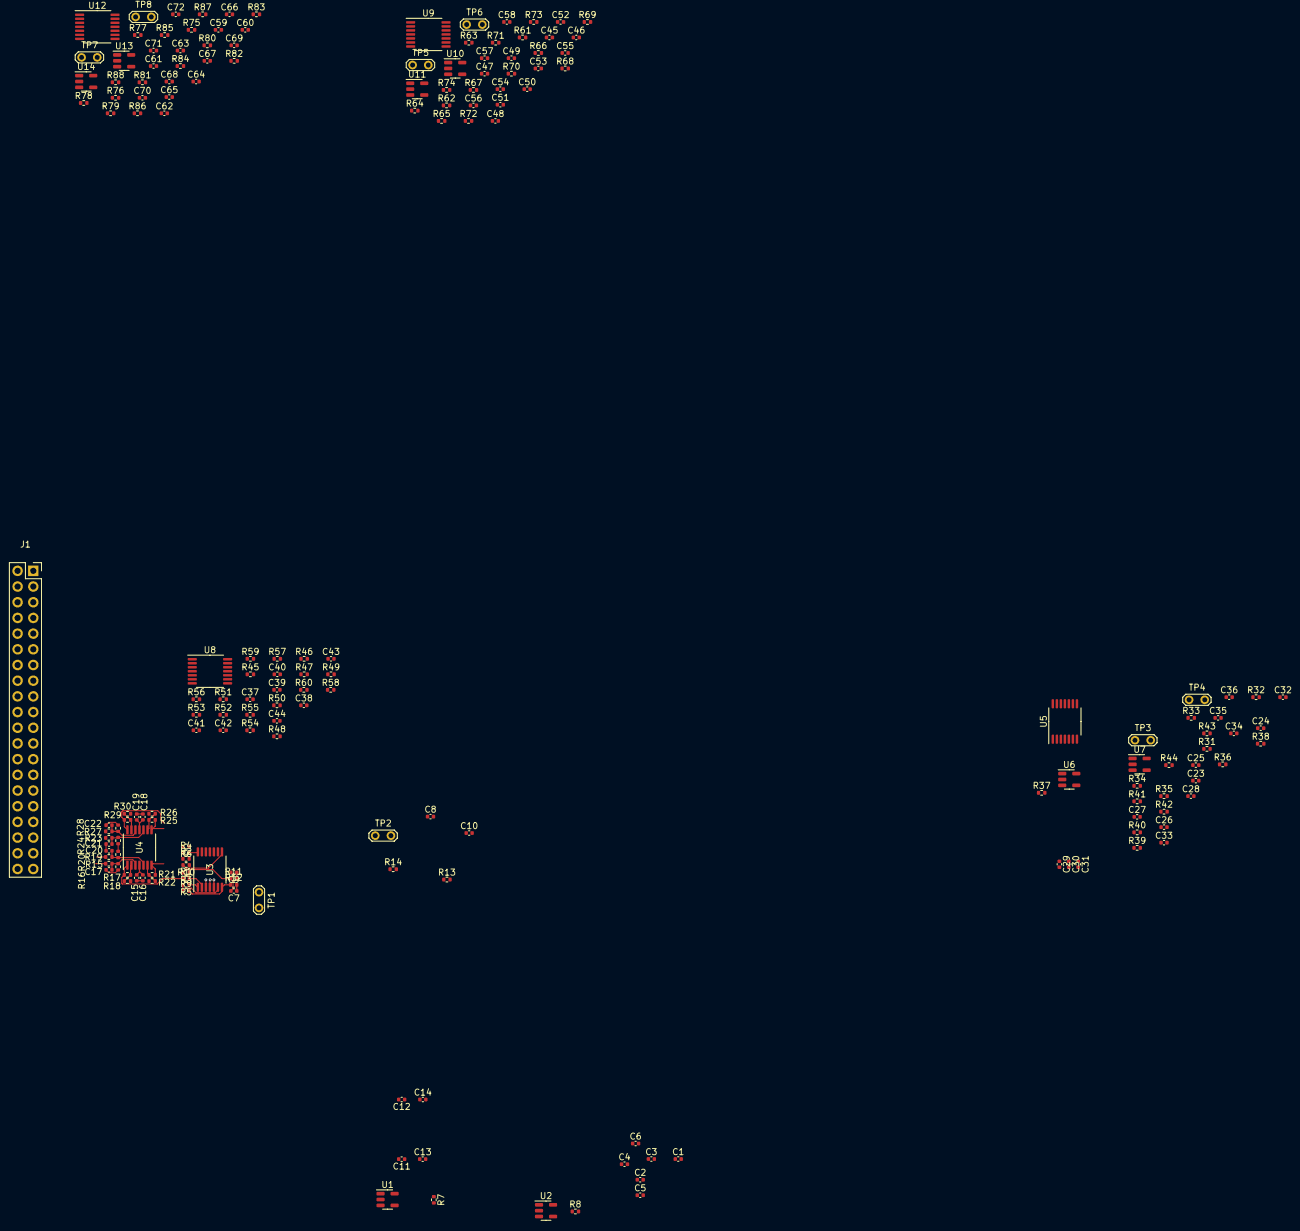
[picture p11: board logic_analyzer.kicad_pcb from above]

Board: 4 copper layers, 183 parts (0 on the bottom side), 93 nets.

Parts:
C1, C2, C29, C34, C51, C56, C65, C70: 100p; C_0402_1005Metric
C3, C4, C30, C35, C52, C57, C66, C71: 10n; C_0402_1005Metric
C5, C6, C31, C36, C53, C58, C67, C72: 1u; C_0402_1005Metric
C7, C8, C9, C10, C25, C26, C32, C33, C47, C48, C54, C55, C61, C62, C68, C69: 30p; C_0402_1005Metric
C11, C12, C15, C18, C23, C27, C37, C40, C45, C49, C59, C63: 100n; C_0402_1005Metric
C13, C14, C16, C19, C24, C28, C38, C41, C46, C50, C60, C64: 10u; C_0402_1005Metric
C17, C20, C21, C22, C39, C42, C43, C44: 70p; C_0402_1005Metric
J1: 3M_8540-4500PL
R1, R2, R34, R41, R64, R71, R78, R85: 1.5k; R_0402_1005Metric
R3, R4, R5, R6, R9, R10, R17, R21, R25, R29, R32, R33, R35, R39, R40, R42, R47, R51, R55, R59, R62, R63, R65, R69, R70, R72, R76, R77, R79, R83, R84, R86: 1k; R_0402_1005Metric
R7, R8, R37, R44, R67, R74, R81, R88: 20; R_0402_1005Metric
R11, R13, R31, R38, R61, R68, R75, R82: 100; R_0402_1005Metric
R12, R14, R36, R43, R66, R73, R80, R87: 150; R_0402_1005Metric
R15, R19, R23, R27, R45, R49, R53, R57: 250; R_0402_1005Metric
R16, R20, R24, R28, R46, R50, R54, R58: 10k; R_0402_1005Metric
R18, R22, R26, R30, R48, R52, R56, R60: 3k; R_0402_1005Metric
TP1, TP2, TP3, TP4, TP5, TP6, TP7, TP8: TestPoint_2Pole; TestPoint_2Pads_Pitch2.54mm_Drill0.8mm
U1, U2, U6, U7, U10, U11, U13, U14: TLV3601; SOT-23-5
U3, U4, U5, U8, U9, U12: ADA4891-4; TSSOP-14_4.4x5mm_P0.65mm

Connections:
+3.3V: C1.1, C2.1, C3.1, C4.1, C5.1, C6.1, C29.1, C30.1, C31.1, C34.1, C35.1, C36.1, C51.1, C52.1, C53.1, C56.1, C57.1, C58.1, C65.1, C66.1, C67.1, C70.1, C71.1, C72.1, U1.5 (V+), U2.5 (V+), U6.5 (V+), U7.5 (V+), U10.5 (V+), U11.5 (V+), U13.5 (V+), U14.5 (V+)
+5V: J1.1 (+5V), J1.39 (+5V)
+5VA: C11.1, C13.1, C15.1, C16.1, C23.1, C24.1, C37.1, C38.1, C45.1, C46.1, C59.1, C60.1, U3.4 (V+), U4.4 (V+), U5.4 (V+), U8.4 (V+), U9.4 (V+), U12.4 (V+)
-5VA: C12.1, C14.1, C18.1, C19.1, C27.1, C28.1, C40.1, C41.1, C49.1, C50.1, C63.1, C64.1, U3.11 (V-), U4.11 (V-), U5.11 (V-), U8.11 (V-), U9.11 (V-), U12.11 (V-)
/BUF_OUT0: R1.1, R17.2, U1.3 (+), U4.1
/BUF_OUT1: R2.1, R21.2, U2.3 (+), U4.7
/BUF_OUT2: R25.2, R34.1, U4.8, U6.3 (+)
/BUF_OUT3: R29.2, R41.1, U4.14, U7.3 (+)
/BUF_OUT4: R47.2, R64.1, U8.1, U10.3 (+)
/BUF_OUT5: R51.2, R71.1, U8.7, U11.3 (+)
/BUF_OUT6: R55.2, R78.1, U8.8, U13.3 (+)
/BUF_OUT7: R59.2, R85.1, U8.14, U14.3 (+)
/Input Section1/ADC_IN+: C25.1, C32.1, R31.2, R38.2, TP3.2, TP4.2
/Input Section1/ADC_IN-: C26.1, C33.1, R36.2, R43.2, TP3.1, TP4.1
/Input Section1/OA1_out: R31.1, R32.2, R35.1, U5.1
/Input Section1/OA2_out: R33.2, R36.1, U5.7
/Input Section1/OA3_out: R38.1, R39.2, R42.1, U5.14
/Input Section1/OA4_out: R40.2, R43.1, U5.8
/Input Section1/Vcom: U5.5 (+), U5.10 (+)
/Input Section2/ADC_IN+: C47.1, C54.1, R61.2, R68.2, TP5.2, TP6.2
/Input Section2/ADC_IN-: C48.1, C55.1, R66.2, R73.2, TP5.1, TP6.1
/Input Section2/OA1_out: R61.1, R62.2, R65.1, U9.1
/Input Section2/OA2_out: R63.2, R66.1, U9.7
/Input Section2/OA3_out: R68.1, R69.2, R72.1, U9.14
/Input Section2/OA4_out: R70.2, R73.1, U9.8
/Input Section2/Vcom: U9.5 (+), U9.10 (+)
/Input Section3/ADC_IN+: C61.1, C68.1, R75.2, R82.2, TP7.2, TP8.2
/Input Section3/ADC_IN-: C62.1, C69.1, R80.2, R87.2, TP7.1, TP8.1
/Input Section3/OA1_out: R75.1, R76.2, R79.1, U12.1
/Input Section3/OA2_out: R77.2, R80.1, U12.7
/Input Section3/OA3_out: R82.1, R83.2, R86.1, U12.14
/Input Section3/OA4_out: R84.2, R87.1, U12.8
/Input Section3/Vcom: U12.5 (+), U12.10 (+)
/Input Section/ADC_IN+: C9.1, C10.1, R11.2, R13.2, TP1.2, TP2.2
/Input Section/ADC_IN-: C7.1, C8.1, R12.2, R14.2, TP1.1, TP2.1
/Input Section/OA1_out: R3.2, R5.1, R11.1, U3.1
/Input Section/OA2_out: R9.2, R12.1, U3.7
/Input Section/OA3_out: R4.2, R6.1, R13.1, U3.14
/Input Section/OA4_out: R10.2, R14.1, U3.8
/Input Section/Vcom: U3.5 (+), U3.10 (+)
/Input Section/Voffset2: U3.3 (+), U3.12 (+), U5.3 (+), U5.12 (+), U9.3 (+), U9.12 (+), U12.3 (+), U12.12 (+)
/Input Section/Vthresh: U1.4 (-), U2.4 (-), U6.4 (-), U7.4 (-), U10.4 (-), U11.4 (-), U13.4 (-), U14.4 (-)
/POD_D0: J1.37 (D0), R15.1
/POD_D1: J1.35 (D1), R19.1
/POD_D2: J1.33 (D2), R23.1
/POD_D3: J1.31 (D3), R27.1
/POD_D4: J1.29 (D4), R45.1
/POD_D5: J1.27 (D5), R49.1
/POD_D6: J1.25 (D6), R53.1
/POD_D7: J1.23 (D7), R57.1
/Voff_buf: R18.1, R22.1, R26.1, R30.1, R48.1, R52.1, R56.1, R60.1
/pod_buf4/BUF_IN0: C17.1, R15.2, R16.2, U4.3 (+)
/pod_buf4/BUF_IN1: C20.1, R19.2, R20.2, U4.5 (+)
/pod_buf4/BUF_IN2: C21.1, R23.2, R24.2, U4.10 (+)
/pod_buf4/BUF_IN3: C22.1, R27.2, R28.2, U4.12 (+)
/pod_buf5/BUF_IN0: C39.1, R45.2, R46.2, U8.3 (+)
/pod_buf5/BUF_IN1: C42.1, R49.2, R50.2, U8.5 (+)
/pod_buf5/BUF_IN2: C43.1, R53.2, R54.2, U8.10 (+)
/pod_buf5/BUF_IN3: C44.1, R57.2, R58.2, U8.12 (+)
GNDA: C7.2, C8.2, C9.2, C10.2, C11.2, C12.2, C13.2, C14.2, C15.2, C16.2, C17.2, C18.2, C19.2, C20.2, C21.2, C22.2, C23.2, C24.2, C25.2, C26.2, C27.2, C28.2, C32.2, C33.2, C37.2, C38.2, C39.2, C40.2, C41.2, C42.2, C43.2, C44.2, C45.2, C46.2, C47.2, C48.2, C49.2, C50.2, C54.2, C55.2, C59.2, C60.2, C61.2, C62.2, C63.2, C64.2, C68.2, C69.2, J1.4 (GND), J1.6 (GND), J1.8 (GND), J1.10 (GND), J1.12 (GND), J1.14 (GND), J1.16 (GND), J1.18 (GND), J1.20 (GND), J1.22 (GND), J1.24 (GND), J1.26 (GND), J1.28 (GND), J1.30 (GND), J1.32 (GND), J1.34 (GND), J1.36 (GND), J1.38 (GND), R16.1, R20.1, R24.1, R28.1, R46.1, R50.1, R54.1, R58.1
GNDD: C1.2, C2.2, C3.2, C4.2, C5.2, C6.2, C29.2, C30.2, C31.2, C34.2, C35.2, C36.2, C51.2, C52.2, C53.2, C56.2, C57.2, C58.2, C65.2, C66.2, C67.2, C70.2, C71.2, C72.2, J1.2 (PGND), J1.40 (PGND), U1.2 (V-), U2.2 (V-), U6.2 (V-), U7.2 (V-), U10.2 (V-), U11.2 (V-), U13.2 (V-), U14.2 (V-)
unnamed: R7.1, U1.1
unnamed: R8.1, U2.1
unnamed: R37.1, U6.1
unnamed: R44.1, U7.1
unnamed: R67.1, U10.1
unnamed: R74.1, U11.1
unnamed: R81.1, U13.1
unnamed: R88.1, U14.1
unnamed: R1.2, R3.1, U3.2 (-)
unnamed: R5.2, R9.1, U3.6 (-)
unnamed: R6.2, R10.1, U3.9 (-)
unnamed: R2.2, R4.1, U3.13 (-)
unnamed: R17.1, R18.2, U4.2 (-)
unnamed: R21.1, R22.2, U4.6 (-)
unnamed: R25.1, R26.2, U4.9 (-)
unnamed: R29.1, R30.2, U4.13 (-)
unnamed: R32.1, R34.2, U5.2 (-)
unnamed: R33.1, R35.2, U5.6 (-)
unnamed: R40.1, R42.2, U5.9 (-)
unnamed: R39.1, R41.2, U5.13 (-)
unnamed: R47.1, R48.2, U8.2 (-)
unnamed: R51.1, R52.2, U8.6 (-)
unnamed: R55.1, R56.2, U8.9 (-)
unnamed: R59.1, R60.2, U8.13 (-)
unnamed: R62.1, R64.2, U9.2 (-)
unnamed: R63.1, R65.2, U9.6 (-)
unnamed: R70.1, R72.2, U9.9 (-)
unnamed: R69.1, R71.2, U9.13 (-)
unnamed: R76.1, R78.2, U12.2 (-)
unnamed: R77.1, R79.2, U12.6 (-)
unnamed: R84.1, R86.2, U12.9 (-)
unnamed: R83.1, R85.2, U12.13 (-)

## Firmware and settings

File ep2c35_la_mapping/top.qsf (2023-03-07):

# -------------------------------------------------------------------------- #
#
# Copyright (C) 1991-2013 Altera Corporation
# Your use of Altera Corporation's design tools, logic functions 
# and other software and tools, and its AMPP partner logic 
# functions, and any output files from any of the foregoing 
# (including device programming or simulation files), and any 
# associated documentation or information are expressly subject 
# to the terms and conditions of the Altera Program License 
# Subscription Agreement, Altera MegaCore Function License 
# Agreement, or other applicable license agreement, including, 
# without limitation, that your use is for the sole purpose of 
# programming logic devices manufactured by Altera and sold by 
# Altera or its authorized distributors.  Please refer to the 
# applicable agreement for further details.
#
# -------------------------------------------------------------------------- #
#
# Quartus II 64-Bit
# Version 13.0.1 Build 232 06/12/2013 Service Pack 1 SJ Web Edition
# Date created = 20:44:42  February 15, 2023
#
# -------------------------------------------------------------------------- #
#
# Notes:
#
# 1) The default values for assignments are stored in the file:
#		top_assignment_defaults.qdf
#    If this file doesn't exist, see file:
#		assignment_defaults.qdf
#
# 2) Altera recommends that you do not modify this file. This
#    file is updated automatically by the Quartus II software
#    and any changes you make may be lost or overwritten.
#
# -------------------------------------------------------------------------- #


set_global_assignment -name FAMILY "Cyclone II"
set_global_assignment -name DEVICE EP2C35F484C8
set_global_assignment -name TOP_LEVEL_ENTITY top
set_global_assignment -name ORIGINAL_QUARTUS_VERSION "13.0 SP1"
set_global_assignment -name PROJECT_CREATION_TIME_DATE "20:44:42  FEBRUARY 15, 2023"
set_global_assignment -name LAST_QUARTUS_VERSION "13.0 SP1"
set_global_assignment -name PROJECT_OUTPUT_DIRECTORY output_files
set_global_assignment -name MIN_CORE_JUNCTION_TEMP 0
set_global_assignment -name MAX_CORE_JUNCTION_TEMP 85
set_global_assignment -name DEVICE_FILTER_PACKAGE FBGA
set_global_assignment -name DEVICE_FILTER_PIN_COUNT 484
set_global_assignment -name DEVICE_FILTER_SPEED_GRADE 8
set_global_assignment -name ERROR_CHECK_FREQUENCY_DIVISOR 1
set_global_assignment -name VERILOG_FILE src/top.v
set_global_assignment -name QIP_FILE models/lvds_tx_4chan_6x.qip
set_global_assignment -name POWER_PRESET_COOLING_SOLUTION "23 MM HEAT SINK WITH 200 LFPM AIRFLOW"
set_global_assignment -name POWER_BOARD_THERMAL_MODEL "NONE (CONSERVATIVE)"
set_global_assignment -name PARTITION_NETLIST_TYPE SOURCE -section_id Top
set_global_assignment -name PARTITION_FITTER_PRESERVATION_LEVEL PLACEMENT_AND_ROUTING -section_id Top
set_global_assignment -name PARTITION_COLOR 16764057 -section_id Top
set_global_assignment -name STRATIX_DEVICE_IO_STANDARD "3.3-V LVTTL"
set_global_assignment -name IOBANK_VCCIO 2.5V -section_id 1
set_global_assignment -name IOBANK_VCCIO 3.3V -section_id 2
set_global_assignment -name IOBANK_VCCIO 3.3V -section_id 3
set_global_assignment -name IOBANK_VCCIO 3.3V -section_id 4
set_instance_assignment -name IO_STANDARD LVDS -to lvds_tx_out[3]
set_instance_assignment -name IO_STANDARD LVDS -to lvds_tx_out[2]
set_instance_assignment -name IO_STANDARD LVDS -to lvds_tx_out[1]
set_instance_assignment -name IO_STANDARD LVDS -to lvds_tx_out[0]
set_instance_assignment -name IO_STANDARD "3.3-V LVCMOS" -to lvds_tx_locked
set_global_assignment -name QIP_FILE models/lvds_rx_10chan_6x.qip
set_global_assignment -name QIP_FILE models/lvds_rx_9chan_6x.qip
set_instance_assignment -name IO_STANDARD LVDS -to lvds_rx_clk0
set_instance_assignment -name IO_STANDARD LVDS -to lvds_rx_clk1
set_instance_assignment -name IO_STANDARD LVDS -to lvds_rx_fclk0
set_instance_assignment -name IO_STANDARD LVDS -to lvds_rx_fclk1
set_instance_assignment -name IO_STANDARD LVDS -to lvds_rx_in0[7]
set_instance_assignment -name IO_STANDARD LVDS -to lvds_rx_in0[6]
set_instance_assignment -name IO_STANDARD LVDS -to lvds_rx_in0[5]
set_instance_assignment -name IO_STANDARD LVDS -to lvds_rx_in0[4]
set_instance_assignment -name IO_STANDARD LVDS -to lvds_rx_in0[3]
set_instance_assignment -name IO_STANDARD LVDS -to lvds_rx_in0[2]
set_instance_assignment -name IO_STANDARD LVDS -to lvds_rx_in0[1]
set_instance_assignment -name IO_STANDARD LVDS -to lvds_rx_in0[0]
set_instance_assignment -name IO_STANDARD LVDS -to lvds_rx_in1[7]
set_instance_assignment -name IO_STANDARD LVDS -to lvds_rx_in1[6]
set_instance_assignment -name IO_STANDARD LVDS -to lvds_rx_in1[5]
set_instance_assignment -name IO_STANDARD LVDS -to lvds_rx_in1[4]
set_instance_assignment -name IO_STANDARD LVDS -to lvds_rx_in1[3]
set_instance_assignment -name IO_STANDARD LVDS -to lvds_rx_in1[2]
set_instance_assignment -name IO_STANDARD LVDS -to lvds_rx_in1[1]
set_instance_assignment -name IO_STANDARD LVDS -to lvds_rx_in1[0]
set_location_assignment PIN_M1 -to lvds_rx_clk0
set_location_assignment PIN_M2 -to "lvds_rx_clk0(n)"
set_location_assignment PIN_Y3 -to lvds_rx_fclk0
set_location_assignment PIN_Y4 -to "lvds_rx_fclk0(n)"
set_location_assignment PIN_N1 -to lvds_rx_in0[0]
set_location_assignment PIN_N2 -to "lvds_rx_in0[0](n)"
set_location_assignment PIN_P1 -to lvds_rx_in0[1]
set_location_assignment PIN_P2 -to "lvds_rx_in0[1](n)"
set_location_assignment PIN_R1 -to lvds_rx_in0[2]
set_location_assignment PIN_R2 -to "lvds_rx_in0[2](n)"
set_location_assignment PIN_T1 -to lvds_rx_in0[3]
set_location_assignment PIN_T2 -to "lvds_rx_in0[3](n)"
set_location_assignment PIN_U1 -to lvds_rx_in0[4]
set_location_assignment PIN_U2 -to "lvds_rx_in0[4](n)"
set_location_assignment PIN_V1 -to lvds_rx_in0[5]
set_location_assignment PIN_V2 -to "lvds_rx_in0[5](n)"
set_location_assignment PIN_W1 -to lvds_rx_in0[6]
set_location_assignment PIN_W2 -to "lvds_rx_in0[6](n)"
set_location_assignment PIN_Y1 -to lvds_rx_in0[7]
set_location_assignment PIN_Y2 -to "lvds_rx_in0[7](n)"
set_location_assignment PIN_Y20 -to lvds_rx_fclk1
set_location_assignment PIN_Y19 -to "lvds_rx_fclk1(n)"
set_location_assignment PIN_Y22 -to lvds_rx_in1[0]
set_location_assignment PIN_Y21 -to "lvds_rx_in1[0](n)"
set_location_assignment PIN_W22 -to lvds_rx_in1[1]
set_location_assignment PIN_W21 -to "lvds_rx_in1[1](n)"
set_location_assignment PIN_V22 -to lvds_rx_in1[2]
set_location_assignment PIN_V21 -to "lvds_rx_in1[2](n)"
set_location_assignment PIN_U22 -to lvds_rx_in1[3]
set_location_assignment PIN_U21 -to "lvds_rx_in1[3](n)"
set_location_assignment PIN_T22 -to lvds_rx_in1[4]
set_location_assignment PIN_T21 -to "lvds_rx_in1[4](n)"
set_location_assignment PIN_R22 -to lvds_rx_in1[5]
set_location_assignment PIN_R21 -to "lvds_rx_in1[5](n)"
set_location_assignment PIN_P22 -to lvds_rx_in1[6]
set_location_assignment PIN_P21 -to "lvds_rx_in1[6](n)"
set_location_assignment PIN_N22 -to lvds_rx_in1[7]
set_location_assignment PIN_N21 -to "lvds_rx_in1[7](n)"
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

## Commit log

2023-02-10 Front-end schematic.
    [input_section.kicad_sch, logic_analyzer.kicad_pcb, logic_analyzer.kicad_sch]
2023-02-13 Probe schematic.
    [hp16550a_probe.kicad_pcb, hp16550a_probe.kicad_sch]
2023-02-13 Rev 1. Before using HP pod.
    [logic_analyzer.kicad_sch]
2023-02-13 Update front-end with new values.
    [input_section.kicad_sch, logic_analyzer.kicad_sch]
2023-02-14 Front-end placement exercise.
    [input_section.kicad_sch, logic_analyzer.kicad_pcb, logic_analyzer.kicad_sch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]
2023-02-21 ep2c35 trial. WIP.
    [ep2c35_trial.kicad_pcb, ep2c35_trial.kicad_sch]
2023-02-27 Wire up FTDI FT600Q.
    [GSB343K331HR.step, ep2c35_trial.kicad_pcb, ep2c35_trial.kicad_sch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]
2023-02-27 Before switching to hierarchical sheets.
    [ep2c35.kicad_sch, ep2c35_trial.kicad_pcb, ep2c35_trial.kicad_sch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]
2023-02-27 Fix tons of ERC violations.
    [ep2c35_trial.kicad_pcb, ep2c35_trial.kicad_sch]
2023-03-02 Power supplies.
    [ep2c35_trial.kicad_pcb, ep2c35_trial.kicad_sch]
2023-03-05 Add digital interface. Power islands.
    [ep2c35_trial.kicad_pcb, ep2c35_trial.kicad_sch]
2023-03-05 Create assembly file. WIP.
    [bom.csv, designators.csv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]
2023-03-06 Move JLCPCB components to bottom.
    [BOM-ep2c35_trial.csv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]
2023-03-07 Add lvds_tx.
    [ep2c35_trial.kicad_pcb, ep2c35_trial.kicad_sch]
2023-03-13 Top ground plan.
    [ep2c35_trial.kicad_pcb, ep2c35_trial.kicad_sch]
2023-03-13 Add ESD protection.
    [ep2c35_trial.kicad_pcb, ep2c35_trial.kicad_sch]
2023-03-13 Add LM317A power regulators.
    [ep2c35_trial.kicad_pcb, ep2c35_trial.kicad_sch]
2023-03-24 Add schematic of a few logic analyzers.
    [hp16550a_probe.kicad_sch]
2023-03-24 Rename la mapping.
2024-03-07 EP2C5 experiment.
    [stp1.stp, stp1_auto_stripped.stp]
2024-03-07 Unknown logic_analyzer changes.
    [input_section.kicad_sch, logic_analyzer.kicad_pcb, logic_analyzer.kicad_sch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]
2024-03-07 hp16550a. Unknown changes.
    [hp16550a_probe.kicad_sch]
2024-03-07 ep2c35_trail. Unknown changes.
    [ep2c35_trial.kicad_pcb]
